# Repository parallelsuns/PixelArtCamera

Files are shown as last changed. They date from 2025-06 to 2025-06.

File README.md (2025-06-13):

Heavily inspired by the [Pixless Camera](https://www.kickstarter.com/projects/carloandreini/pixless-camera), the Pixel Art Camera is a portable ‘toy’ camera that takes lo-resolution photos and posterizes the pixel colors to a small limited color palette, typically used for pixel art. This creates photos that resemble retro pixel art.

The camera supports .hex color palette files downloadable from https://lospec.com/palette-list.

The camera is built with a Waveshare ESP32-S3-Touch-LCD-2 development board, an OV5640 camera module and a 400 mAh Li-Po battery with a 3d printed enclosure.

For example images: https://parallelsuns.com/pixel-art-camera/

The code isn't very clean as this was just a fun side-project. You have been warned! 

Also, I did not bother with computing an accurate battery percentage based on the discharge curve or anything so the battery percentage indicator is VERY VERY approximate.

## Usage Instructions

See https://github.com/parallelsuns/PixelArtCamera/blob/main/User_Manual.md

## Building

Build using Arduino IDE 2.3.6. You should set up the build environment following Waveshare's instructions provided here: https://www.waveshare.com/wiki/ESP32-S3-Touch-LCD-2#Environment_Setup.

Ensure you are able to build the example projects provided.

You'll need the cst816 library, which can be found as part of the 'offline component package' linked at the bottom of the page linked above.

## Requirements

| Library | Version | Remarks |
| --- | --- | --- |
| [LVGL](https://lvgl.io/) | 8.4.0 | |
| [Arduino_GFX](https://github.com/moononournation/Arduino_GFX) | 1.5.9 | |
| [bsp_cst816](https://drive.google.com/drive/folders/1Pcs_A4FKWvdSHnz9lEBYqOpr-noTMbIv) | N.A. | Not available in Arduino IDE. Provided by Waveshare. |

## BOM

| Part | Source | Remarks |
| --- | --- | --- |
| Waveshare ESP32-S3-Touch-LCD-2-C | https://www.waveshare.com/product/arduino/boards-kits/esp32/esp32-s3-touch-lcd-2.htm?sku=29668 | |
| OV5640 Camera Module | https://www.waveshare.com/product/arduino/boards-kits/esp32/esp32-s3-touch-lcd-2.htm?sku=29668 | (Optionally bundled with the ESP32-S3-Touch-LCD-2-C from above URL) |
| 400 mAh 3.7v Li-Po Battery (dimensions approx 48x16x5mm) | https://kuriosity.sg/products/3-7v-li-po-lithium-polymer-battery-100mah-400mah-600mah-1600mah-2000mah-5000mah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 | Any Li-Po battery works. If you wish to use the 3d printed case STL the battery should fit within the give dimensions |
| SPST Rocker Switch (mounting hole 13x9mm) | https://www.amazon.com/DIYhz-Environmental-Protection-Electrical-Products/dp/B07BPKZ2RG | Switch should match given mounting dimensions to work with the 3d printed case STL |
| 3d Printed Enclosure | https://github.com/parallelsuns/PixelArtCamera/blob/main/PixelArtCamera_enclosure.stl | PLA 15% infill should work just fine |

## Assembly

1. Print 3d printed enclosure.
2. Mount the rocker switch into case.
3. Insert battery into the compartment in the case.
4. Cut 1 lead from the battery and solder the rocker switch in between the 2 halves.
5. Connect the battery to VBAT and G on the ESP32 board.
6. Slide the board into the enclosure. Secure it with adhesive/screws.
7. Compile the firmware and flash it via USB.

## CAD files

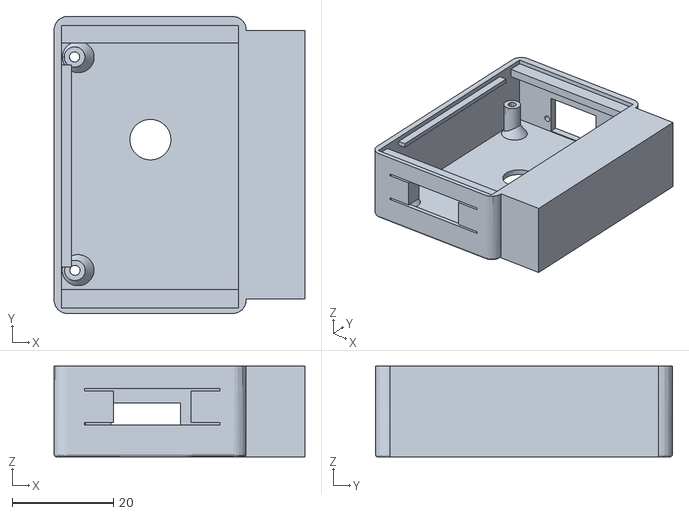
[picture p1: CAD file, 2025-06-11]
PixelArtCamera_enclosure.stl
49.6 x 58.8 x 18.0

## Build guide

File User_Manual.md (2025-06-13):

## Taking A Photo
1. Turn on the camera.
2. Select a color palette using the 'Color' button. See "Adding Color Palettes" to add more color palettes. The palette colors are shown in small circles below the camera display on the main page.
3. Press 'Capture' to capture a photo. After capturing, the display will show the transformed photo.
4. Press anywhere on the screen to dismiss the captured photo.

## Adjusting Camera Settings
1. Press the 'Camera' button in the top left to access various camera settings.

## Adding Color Palettes
1. Visit https://lospec.com/palette-list to browse and download palettes. Download them in .HEX file format.
2. Connect the camera to your computer via USB.
3. Press the 'USB' button on the top of the display. This will mount the onboard storage as a removable drive. NOTE: The USB interface is quite slow and it may take up to a minute for the removable drive to be fully detected and readable.
4. Transfer the downloaded .HEX palettes into the folder "palette".
5. Disconnect the camera and turn it on. The palettes should now be selectable in the color palettes page.

## Transferring Photos
1. Connect the camera to your computer via USB.
2. Press the 'USB' button on the top of the display. This will mount the onboard storage as a removable drive. NOTE: The USB interface is quite slow and it may take up to a minute for the removable drive to be fully detected and readable.
3. All photos taken will be in the root director, in JPG format.
4. If there are compatibility issues with your computer, you can also physically remove the onboard microSD card and insert it into a memory card reader. You can do so by slowly pulling the display and the attached circuit board off of the enclosure. BE CAREFUL! If you exert too much force you might detach the display from the circuit board and possibly break it. You should only use this method as a last resort. Try using a different computer first before doing this.

## Charging The Battery
1. Connect the camera to a USB charger or to a computer via USB.
2. IMPORTANT: Ensure the power switch is turned on. The battery is now charging.
3. NOTE: The battery % indicator is VERY INACCURATE and should only be used as an estimate.

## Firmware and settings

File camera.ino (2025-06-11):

/*Using LVGL with Arduino requires some extra steps:
 *Be sure to read the docs here: https://docs.lvgl.io/master/get-started/platforms/arduino.html  */
#include "globals.h"
#include "lv_conf.h"
#include "esp_camera.h"
#include <lvgl.h>
#include <stdio.h>
#include "sd_fns.h"
#include "camera_params.h"
#include "img.h"
#include "ui_fns.h"


static void on_capture(lv_event_t * e) {
  capture_pressed = true;
}

static void on_usb(lv_event_t* e) {
  ((Arduino_ST7789*)gfx)->displayOff();
  lvgl_lock(-1);
  bus->endWrite();
  digitalWrite(PIN_NUM_LCD_CS, HIGH);
  vTaskDelay(pdMS_TO_TICKS(5));

  MSC.vendorID("PllSuns");       //max 8 chars
  MSC.productID("PixArtCam");    //max 16 chars
  MSC.productRevision("1.0");  //max 4 chars
  MSC.onStartStop(onStartStop);
  MSC.onRead(onRead);
  MSC.onWrite(onWrite);

  MSC.mediaPresent(true);
  MSC.isWritable(true);  // true if writable, false if read-only

  Serial.println("Mount USB");
  Serial.println("SD Size: ");
  Serial.println(SD.cardSize());
  Serial.println("Sector Size: ");
  Serial.println(SD.sectorSize());

  vTaskDelay(pdMS_TO_TICKS(10));

  if (!USB.begin()) Serial.println("USB Begin Failed");
  if (!MSC.begin(SD.numSectors() , SD.sectorSize())) Serial.println("USBMC Begin Failed");
  
}

#if LV_USE_LOG != 0
/* Serial debugging */
void my_print(const char *buf) {
  if (DEBUG) Serial.printf(buf);
  if (DEBUG) Serial.flush();
}
#endif

/* Display flushing */
void my_disp_flush(lv_disp_drv_t *disp_drv, const lv_area_t *area, lv_color_t *color_p) {
#if (LV_COLOR_16_SWAP != 0)
  gfx->draw16bitBeRGBBitmap(0, 0, (uint16_t *)disp_draw_buf, LCD_H_RES, LCD_V_RES);
#else
  gfx->draw16bitRGBBitmap(0, 0, (uint16_t *)disp_draw_buf, LCD_H_RES, LCD_V_RES);
#endif
  lv_disp_flush_ready(disp_drv);
}

/*Read the touchpad*/
void my_touchpad_read(lv_indev_drv_t *indev_drv, lv_indev_data_t *data) {
  uint16_t touchpad_x;
  uint16_t touchpad_y;
  bsp_touch_read();

  if (bsp_touch_get_coordinates(&touchpad_x, &touchpad_y)) {
    data->point.x = touchpad_x;
    data->point.y = touchpad_y;
    data->state = LV_INDEV_STATE_PRESSED;
    showing_captured = false;
  } else {
    data->state = LV_INDEV_STATE_RELEASED;
  }

}

void lvgl_camera_ui_init(lv_obj_t *parent) {
  img_camera = lv_img_create(parent);
  lv_obj_align(img_camera, LV_ALIGN_CENTER, 0, 0);
  lv_obj_set_pos(img_camera, 0, 0);
  lv_obj_set_scroll_dir(parent, LV_DIR_NONE);

  lv_obj_set_style_pad_top(img_camera, 0, LV_PART_MAIN);
  lv_obj_set_style_pad_bottom(img_camera, 0, LV_PART_MAIN);
  lv_obj_set_style_pad_left(img_camera, 0, LV_PART_MAIN);
  lv_obj_set_style_pad_right(img_camera, 0, LV_PART_MAIN);
}

void update_voltage() {
  char str_buffer[20];
  float voltage;
  uint16_t analogValue = analogRead(5);
  voltage = 3.3 / 4096 * analogValue * 3;
  if (batt_voltage == 0) batt_voltage = voltage;
  else batt_voltage = 0.98 * batt_voltage + voltage * 0.02;
  sprintf(str_buffer, "%d \%", int(((batt_voltage - 3) / 0.7) * 100));
  strcat(str_buffer, "%");
  lv_label_set_text(batt_label, str_buffer);
}

static void task(void *param) {
  camera_config_t config;
  config.ledc_channel = LEDC_CHANNEL_0;
  config.ledc_timer = LEDC_TIMER_1;
  config.pin_d0 = Y2_GPIO_NUM;
  config.pin_d1 = Y3_GPIO_NUM;
  config.pin_d2 = Y4_GPIO_NUM;
  config.pin_d3 = Y5_GPIO_NUM;
  config.pin_d4 = Y6_GPIO_NUM;
  config.pin_d5 = Y7_GPIO_NUM;
  config.pin_d6 = Y8_GPIO_NUM;
  config.pin_d7 = Y9_GPIO_NUM;
  config.pin_xclk = XCLK_GPIO_NUM;
  config.pin_pclk = PCLK_GPIO_NUM;
  config.pin_vsync = VSYNC_GPIO_NUM;
  config.pin_href = HREF_GPIO_NUM;
  config.pin_sccb_sda = SIOD_GPIO_NUM;
  config.pin_sccb_scl = SIOC_GPIO_NUM;
  config.pin_pwdn = PWDN_GPIO_NUM;
  config.pin_reset = RESET_GPIO_NUM;
  config.xclk_freq_hz = 20000000;
  config.frame_size = FRAMESIZE_HQVGA;
  config.pixel_format = PIXFORMAT_RGB565;
  config.grab_mode = CAMERA_GRAB_WHEN_EMPTY;
  config.fb_location = CAMERA_FB_IN_PSRAM;
  config.jpeg_quality = 12;
  config.fb_count = 1;

  esp_err_t err = esp_camera_init(&config);
  if (err != ESP_OK) {
    Serial.printf("Camera init failed with error 0x%x", err);
    vTaskDelete(NULL);
    return;
  }

  sensor_t * s = esp_camera_sensor_get();
  s->set_hmirror(s, 1);

  init_settings_page();

  camera_fb_t *pic;
  lv_img_dsc_t img_dsc;
  img_dsc.header.always_zero = 0;
  img_dsc.header.w = QVGA_W;
  img_dsc.header.h = QVGA_H;
  img_dsc.data_size = QVGA_W * QVGA_H * 2;
  img_dsc.header.cf = LV_IMG_CF_TRUE_COLOR;
  img_dsc.data = NULL;

  while (1) {
    pic = esp_camera_fb_get();

    if (capture_pressed) {
      capture_pressed = false;
      if (!sd_active) {
        save_to_sd(pic);
      }
    }

    if (showing_captured && processed_img_disp_buf) {
      img_dsc.data = processed_img_disp_buf;
      if (lvgl_lock(-1)) {
        lv_img_set_src(img_camera, &img_dsc);
        lvgl_unlock();
      }
    }
    else if (NULL != pic) {
      img_dsc.data = pic->buf;
      if (lvgl_lock(-1)) {
        lv_img_set_src(img_camera, &img_dsc);
        lvgl_unlock();
      }

    }
    update_voltage();

    esp_camera_fb_return(pic);
    vTaskDelay(pdMS_TO_TICKS(1));
  }
  vTaskDelete(NULL);
}

void setup() {

  Serial.begin(115200);
  lvgl_api_mux = xSemaphoreCreateRecursiveMutex();
  Serial.println("Arduino_GFX LVGL_Arduino_v8 example ");
  String LVGL_Arduino = String('V') + lv_version_major() + "." + lv_version_minor() + "." + lv_version_patch();
  Serial.println(LVGL_Arduino);

  processed_img_disp_buf = (uint8_t*)malloc(QVGA_W * QVGA_H * 2);
  
  
#ifdef GFX_EXTRA_PRE_INIT
  GFX_EXTRA_PRE_INIT();
#endif

  //init cs pin for sd
  pinMode(PIN_NUM_SD_CS, OUTPUT);
  digitalWrite(PIN_NUM_SD_CS, HIGH);

  // Init Display
  if (!gfx->begin()) {
    Serial.println("gfx->begin() failed!");
  
  }
  //Init SD
  SPI.begin(PIN_NUM_SD_SCLK, PIN_NUM_SD_MISO, PIN_NUM_SD_MOSI, PIN_NUM_SD_CS);
  if (!SD.begin(PIN_NUM_SD_CS, SPI, 80000000))
  {
      Serial.println("SD Card Mount Failed");
      return;
  }
  else Serial.println("SD Card Mount Succeeded.");

#ifdef PIN_NUM_LCD_BL
  ledcAttach(PIN_NUM_LCD_BL, LEDC_FREQ, LEDC_TIMER_10_BIT);
  ledcWrite(PIN_NUM_LCD_BL, (1 << LEDC_TIMER_10_BIT) / 100 * 80);
#endif

  // Init touch device
  Wire.begin(PIN_NUM_TP_SDA, PIN_NUM_TP_SCL);
  bsp_touch_init(&Wire, gfx->getRotation(), gfx->width(), gfx->height());
  lv_init();

#if LV_USE_LOG != 0
  lv_log_register_print_cb(my_print); /* register print function for debugging */
#endif

  disp_draw_buf = (lv_color_t *)heap_caps_malloc(LCD_H_RES * LCD_V_RES * 2, MALLOC_CAP_INTERNAL | MALLOC_CAP_8BIT);
  if (!disp_draw_buf) {
    // remove MALLOC_CAP_INTERNAL flag try again
    disp_draw_buf = (lv_color_t *)heap_caps_malloc(LCD_H_RES * LCD_V_RES * 2, MALLOC_CAP_8BIT);
  }

  if (!disp_draw_buf) {
    Serial.println("LVGL disp_draw_buf allocate failed!");
  } else {
    lv_disp_draw_buf_init(&draw_buf, disp_draw_buf, NULL, LCD_H_RES * LCD_V_RES);
    
    /* Initialize the display */
    lv_disp_drv_init(&disp_drv);
    disp_drv.hor_res = gfx->width();
    disp_drv.ver_res = gfx->height();
    disp_drv.flush_cb = my_disp_flush;
    disp_drv.draw_buf = &draw_buf;
    disp_drv.direct_mode = true;

    lv_disp_drv_register(&disp_drv);

    /* Initialize the (dummy) input device driver */
    static lv_indev_drv_t indev_drv;
    lv_indev_drv_init(&indev_drv);
    indev_drv.type = LV_INDEV_TYPE_POINTER;
    indev_drv.read_cb = my_touchpad_read;
    lv_indev_drv_register(&indev_drv);
  }

  ui_pages[UIScreen::MAIN] = lv_obj_create(NULL);
  ui_pages[UIScreen::PALETTE_LIST] = lv_obj_create(NULL);
  ui_pages[UIScreen::CAMERA_PARAMS] = lv_obj_create(NULL);

  lvgl_camera_ui_init(ui_pages[UIScreen::MAIN]);
  lv_scr_load(ui_pages[UIScreen::MAIN]);
  gfx->fillScreen(BLACK);
  
  init_main_page();
  init_palette();
  init_palette_ui();
  load_last_palette();
  find_next_file_index();

  Serial.println("Setup done");
  
  xTaskCreatePinnedToCore(
    task,
    "lvgl_app_task",
    1024 * 10,
    NULL,
    1,
    NULL,
    0);
}

void loop() {
  if (lvgl_lock(-1)) {
    lv_timer_handler(); /* let the fxUI do its work */
    lvgl_unlock();
  }
  vTaskDelay(pdMS_TO_TICKS(5));
}

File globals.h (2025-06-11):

#ifndef INCLUDEH
#define INCLUDEH

#include <Arduino_GFX_Library.h>
#include <lvgl.h>
#include "bsp_cst816.h"
#include "FS.h"
#include "SD.h"
#include "SPI.h"
#include "USB.h"
#include "USBMSC.h"

#define INT_MAX 21474836

//GPIO Defs
#define PWDN_GPIO_NUM 17   //power down is not used
#define RESET_GPIO_NUM -1  //software reset will be performed
#define XCLK_GPIO_NUM 8
#define SIOD_GPIO_NUM 21
#define SIOC_GPIO_NUM 16
#define Y9_GPIO_NUM 2
#define Y8_GPIO_NUM 7
#define Y7_GPIO_NUM 10
#define Y6_GPIO_NUM 14
#define Y5_GPIO_NUM 11
#define Y4_GPIO_NUM 15
#define Y3_GPIO_NUM 13
#define Y2_GPIO_NUM 12
#define VSYNC_GPIO_NUM 6
#define HREF_GPIO_NUM 4
#define PCLK_GPIO_NUM 9
#define PIN_NUM_LCD_SCLK 39
#define PIN_NUM_LCD_MOSI 38
#define PIN_NUM_LCD_MISO 40
#define PIN_NUM_LCD_DC 42
#define PIN_NUM_LCD_RST -1
#define PIN_NUM_LCD_CS 45
#define PIN_NUM_SD_SCLK 39
#define PIN_NUM_SD_MOSI 38
#define PIN_NUM_SD_MISO 40
#define PIN_NUM_SD_CS 41
#define PIN_NUM_LCD_BL 1
#define PIN_NUM_TP_SDA 48
#define PIN_NUM_TP_SCL 47
#define LCD_ROTATION 0
#define LEDC_FREQ 5000
#define LEDC_TIMER_10_BIT 10

//LCD RES
#define LCD_H_RES 240
#define LCD_V_RES 320
//Camera Res
#define QVGA_W 240
#define QVGA_H 176

//mutex for lvgl's render loop
static SemaphoreHandle_t lvgl_api_mux = NULL;

//LCD SPI Bus and Wrapper Class
static Arduino_DataBus *bus = new Arduino_ESP32SPI(
  PIN_NUM_LCD_DC /* DC */, PIN_NUM_LCD_CS /* CS */,
  PIN_NUM_LCD_SCLK /* SCK */, PIN_NUM_LCD_MOSI /* MOSI */, GFX_NOT_DEFINED /* MISO */, FSPI, true);
static Arduino_GFX *gfx = new Arduino_ST7789(
  bus, PIN_NUM_LCD_RST /* RST */, LCD_ROTATION /* rotation */, true /* IPS */,
  LCD_H_RES /* width */, LCD_V_RES /* height */);

//USB Mass Storage Controller
static USBMSC MSC;

enum UIScreen {
  MAIN,
  PALETTE_LIST,
  ALBUM, //unimplemented
  CAMERA_PARAMS,
  IMG_FX, //unimplemented
  INVALID,
};

//ui page objects
static lv_obj_t* ui_pages[UIScreen::INVALID];
static UIScreen current_ui_page = UIScreen::MAIN;

//main page ui objects
static lv_obj_t* img_camera;
static lv_obj_t* batt_label;
static lv_obj_t* palette_label;
static lv_obj_t* album_img;
static float batt_voltage = 0; //current battery voltage estimate
static lv_disp_draw_buf_t draw_buf;
static lv_color_t *disp_draw_buf;
static lv_disp_drv_t disp_drv;
static bool capture_pressed = false; //true when capture button is pressed, back to false after img processed
static uint8_t* processed_img_disp_buf = nullptr;
static bool showing_captured = false;

//camera params page ui objects
static lv_obj_t * wb_label;

//image processing vars
static int curr_scale_factor = 4; //img is scaled by this factor before saving to jpg, beyond 4 we run the risk of running out of memory
static int dither_pattern = 0; //unimplemented
static int8_t dither_strength = 0; //unimplemented

//sd card saving vars
static bool sd_active = false;
static int curr_file_index = 0;

struct Color {
  uint8_t r;
  uint8_t g;
  uint8_t b;
};

struct Palette { 
  uint8_t len;
  Color p[256];
  char name[256];
  lv_obj_t* leds[256];
  lv_style_t style;
};

static Palette curr_palette;

//locks lvgl mutex
static bool lvgl_lock(int timeout_ms) {
  // Convert timeout in milliseconds to FreeRTOS ticks
  // If `timeout_ms` is set to -1, the program will block until the condition is met
  const TickType_t timeout_ticks = (timeout_ms == -1) ? portMAX_DELAY : pdMS_TO_TICKS(timeout_ms);
  return xSemaphoreTakeRecursive(lvgl_api_mux, timeout_ticks) == pdTRUE;
}

//unlock lvgl mutex
static void lvgl_unlock(void) {
  xSemaphoreGiveRecursive(lvgl_api_mux);
}

static void on_return_to_main(lv_event_t* e) {
  lv_scr_load(ui_pages[UIScreen::MAIN]);
}

static void sd_activate() {
  lvgl_lock(-1);
  sd_active = true;
  bus->endWrite();
  digitalWrite(PIN_NUM_LCD_CS, HIGH);
  digitalWrite(PIN_NUM_SD_CS, LOW);
  vTaskDelay(pdMS_TO_TICKS(10));
}

static void sd_deactivate() {
  digitalWrite(PIN_NUM_SD_CS, HIGH);
  digitalWrite(PIN_NUM_LCD_CS, LOW);
  SPI.endTransaction();
  lvgl_unlock();
  sd_active = false;
}

#endif
